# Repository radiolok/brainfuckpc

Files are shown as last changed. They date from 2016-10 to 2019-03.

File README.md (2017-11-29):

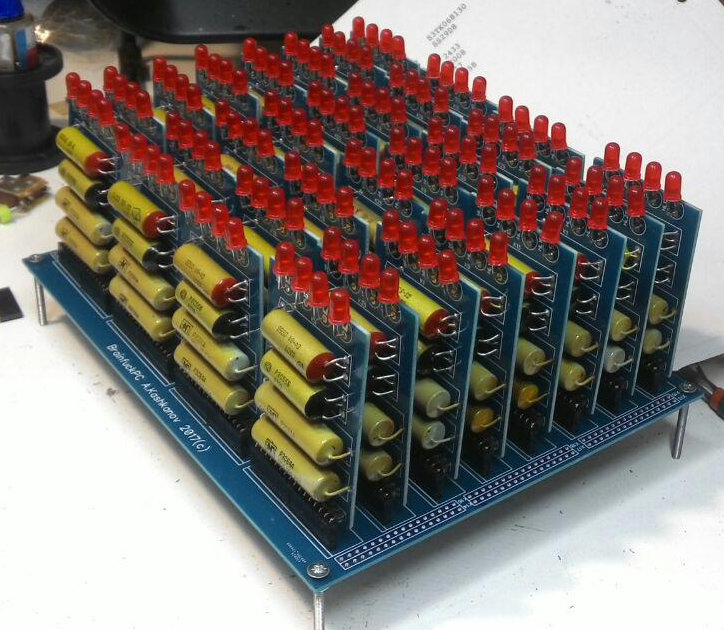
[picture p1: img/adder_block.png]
Adder block


Adder block photo

# GENERAL INFORMATION

* Von-neuman 16-bit architecture

* Brainfuck instruction set with RLE support and additional commands [(see instruction set DRAFT)](/doc/instruction_set.md)

* 16-bit Address space - rev.1 would use 65536 x 16 SRAM, rev.2 would have ferrite core memory;

* 16-bit Instruction length;

* 16-bit Data, with 8-bit backward-compatibility mode for executing 8-bit programms;

* Use reed relay only - soviet RES55 and RES64;

* One adder - 256 relays, 4 registers - 48 relay each, and instruction decoding logic takes about 200 relays ~= 700 relays.

* Clock frequency up to 100 Hz.

# BRAINFUCK

Brainfuck is an esoteric programming language created in 1993 by Urban Müller, and notable for its extreme minimalism.

The language consists of only eight simple commands and an instruction pointer. While it is fully Turing-complete, it is not intended for practical use, but to challenge and amuse programmers.

The language's name is a reference to the slang term brainfuck, which refers to things so complicated or unusual that they exceed the limits of one's understanding.

Classic Brainfuck arch has eight commands:

* \>	increment the address pointer (to point to the next cell to the right).

* <	decrement the address pointer (to point to the next cell to the left).

* \+	increment (increase by one) the byte at the address pointer.

* \-	decrement (decrease by one) the byte at the address pointer.

* .	output the byte at the address pointer.

* ,	accept one byte of input, storing its value in the byte at the address pointer.

* \[	if the byte at the address pointer is zero, then instead of moving the instruction pointer forward to the next command, jump it forward to the command after the matching ] command.

* ]	if the byte at the address pointer is nonzero, then instead of moving the instruction pointer forward to the next command, jump it back to the command after the matching \[ command.

As each relay has very big latency I add RLE compressing of +- and <> commands.

If source file contain "+++++" or "-----" sequence, when listing will be loaded this sequence will be transformed into "+Constant" command - My computer has fully - functionaland 16-bit Adder for Data/Address/Instruction and this hack improve computer performance in many times.

Loop command are work as JZ to the end of the cycle and JNZ to begin using second Adder input and 12-bit jump

Use DipTrace 2.3 or higher  to open project files

Use Splan 7 to open spl7 files - there are some structures.

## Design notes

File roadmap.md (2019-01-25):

# 1. PCB Making[DEPRACATED]

I have no time to finish self-maid boards so ordered full set of pcb's:
10 pcb - base boards
10 plates with 24 different modules on each - 240 modules
2AND/2XOR
2AND/2OR
D-trigger
2&(3C+1A)
Diode(8)

## Equipment
1. Roaster temperature regulator - Done
2. Solder mask frame table   - Done
3. Etching bath - Ok
4. CNC milling machine tuning - Not finished yet
5. 3D printer - In use

# 2. Soldering
| Module | Components  | Soldered | Status |
|---|---|---|---|
|2AND/2OR |  Check  | 22 |  Done |
|2AND/2XOR |  Check  | 32 |  Done |
|D-TRIGGER |  Check | 67 |  Done |
|2& | Check  | 20 |  Done |
|Diode module |  Check  | 20 |  Done |
|Base board |  Check | 5/6 |  Done |
|Memory board |  Check | 1/1 |  Done |
|Indicator module |  Check | 4/4 |  Done |
|Latch module |  Check | 8/8 |  Done |

## Equipment
1. Relay tester - Done
2. Modules tester - Done

# 3. Wire Wrapping
|Block | Status | 
|---|---|
|ADD |  DONE  |
|IP/AP REG |  DONE  |
|TMP/CMD REG |  DONE  |
|LOGIC BLOCK |  Active |
|LOGIC/SWITCH BLOCK  |  Active  |

# 4. Memory Board 
| Operation |  Status |
|---|---|
| Schematic |  Done |
| PCB Routing |  Done |
| MCU firmware |  Active  |

# 5. Housing
|  Component | Status |
|---|---|
| Base Plate | Done |
| Main Frame | Done |

# 6. Progress updates:

## Update 12/1/2019:
* BFPC Frame is done, and all computer parts are placed on chassis;
* Memory board is working enough for BFPC start;
* Logic blocks are 30% done

## Update 24/05/2018:
* D-triggers for TMP/CMD register block done;
* All block housings are printed;
* Indicator boards assembly finished;
* Soldered all latch modules;

## Update 26/02/2018:
* Adder Block done and tested;
* IP/AP register block done and tested;
* Continue soldering D-trigger modules;
* Created indicator modules. Soldered two of them. Fw for one is done;
* Created latch modules. Soldered two of them;
* Start working with memory board firmware.

## Update 14/12/2017:
* Soldering D-trigger modules. Need 64+, got half of them
* Designed indicator board
* Start wire-wrap of adder block

## Update 12/11/2017:
* Ordered pcbs from easyeda and got it.
* Soldered all 2AND/2XOR modules for carry-chain adder. Start soldering base plate for it.
* Done with modules tester - didn't check any relay but will check all modules.

## Update 05/06/2017:
* Only in third attempt I painted some boards with solder mask. It's a diode module, 2ANDx4 module and 2& module - two plates of each type. Currently can start drill and mill them and start assemble the modules.

## Update 17/04/2017:
* Rework and optimized ADDer logic. previous version needed 64 modules with 3 different types: ADD+C, 5AND, 2AND/2OR. New version need 32 modules with 2AND/2XOR type; One basic block would be used for latches.
* Done with memory Board module routing - Already got ready pcb from manufacturer and currently soldering it.
* Done with prepearing for solder mask operations - will start with this one as soon possible;
* Thinking about memory module firmware. Start developing it's arch.

## Update 08/03/2017:
* I'm done with all known modules etching 30 pcbs! All adder modules, all register modules are ecthed;
* Created and etched some modules for logic block - I have 64 modules capacity on it and have only preliminarty schematic for microcode;
* Next step - apply solder mask on them and send to drilling and milling. After this steps I will start soldering modules.

## Update 04/03/2017:
* Put image on another 6 plates and want to etch them in near future - 3x5AND, 1x2AND/2OR, 2xD-trigger.
* Almost finished with Memory Board routing. Need to fix power lines and check all connections.
* Prepare plywood table for photomask - it's ready for use and I want to start when finished with all known boards.

## Update 25/02/2017:
* Etched additional 12 pcb's - 6 pcb of D-trigger, 2 ADD+C, 1 5AND, 3 base boards.

## Update 23/02/2017:
* Suddenly found that I have D-trigger unrouted yet. Fix this issue and got one-side pcb with one jumper. Printed Photomasks and Imaged two plates;
* Modified ADD+C routing into one-side pcb with one jumper. Reprinted photomasks and made one of two Images;
* Bought thermal laminator for doing photoresist operations better - when I start etching I found that they are a lot of issues with images quality. First test gaves me stable good image quality after I just found proper temperature;
* Currently I have 5 etched plates and 7 - waiting for etch (will do it in 2-3 days).

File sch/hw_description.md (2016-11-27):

#Parts

Computer consists of many different unified basic modules 60x44mm with 16x2.54mm male socket. 
Each module contains 4 reed relays, status LED's and diode binding for each relay.

## Modules types:

* 1bit ADD+C module for adder - 16 modules;
* 5AND module for parallel carry - 32 modules;
* Universal 2AND/2OR module for adder and control logic - 16 modules(for Adder);
* 1bit D-trigger with inversion for temp register - 16 modules;
* 1bit D-trigger with Output switch, for IP and AP register, Bias register and command register - 48 modules;
* Some other modules, which I din't implemented yet (list is updated)

## Base Plates:

Modules are mounted on base plates, 32 modules on each 150x200m base plate. Current implementation requers 7 base plates:

* Base plate with 32 16pin connectiors - 5 base plates;
* Switching plate with only 8 16-pin connectors, but with 4 16 bit switches - 1 plate;
* Memory plate with static RAM IC, input and output buffers and MCU with LED drivers for LED 16x32dot disdplay;

I will made all connection with wire-wrapping method.

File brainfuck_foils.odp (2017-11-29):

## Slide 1

16-bit

FULL ADDER with CARRY

IP REG

AP REG

(16bit)

RAM, CIN, COUT

MCU loader, LED display,

Wi-Fi& USB Connection

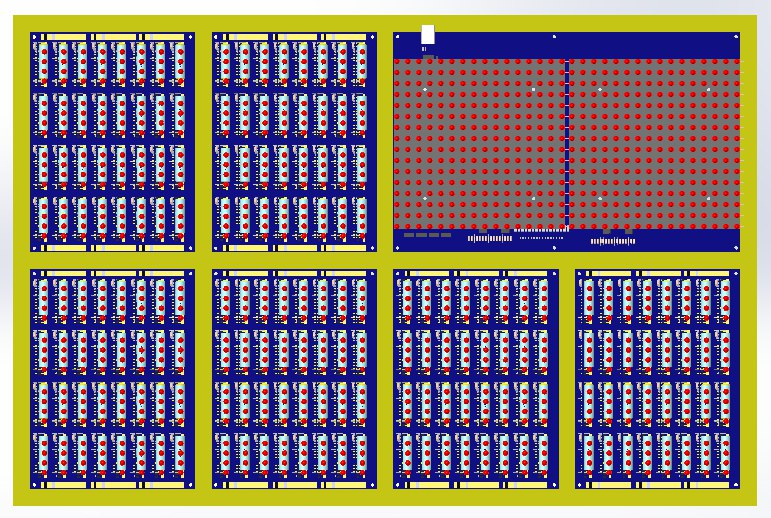
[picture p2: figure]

TMP REG

(16bit)

CMD REG

(12+4bit)

SEQUENCER,

CMD SELECTOR

and some other logic

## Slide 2

ADDRESS BUS

TMP

REG

16bit

IP

REG

16bit

RAM

64K

x16bit

COUT

CIN

ADDER

+

CARRY

AP

REG

16bit

CMD

REG

12bit

4bit

LOGIC

DATA BUS

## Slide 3

RAM Main Flow

Address input buffer

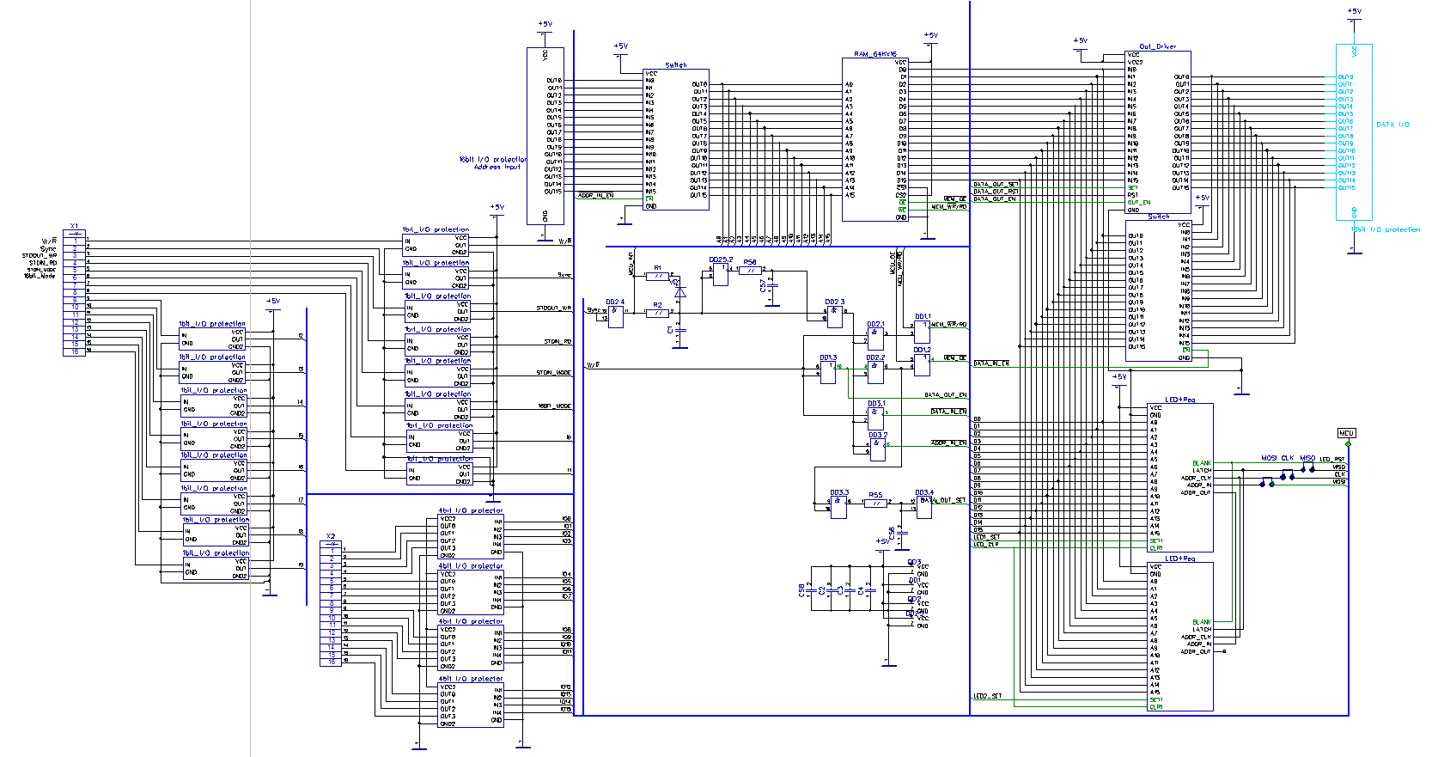
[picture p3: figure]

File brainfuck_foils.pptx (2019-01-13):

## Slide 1

16-bit
FULL ADDER with CARRY

IP REG
AP REG
(16bit)

RAM, CIN, COUT
MCU loader, LED display,
Wi-Fi& USB Connection


TMP REG
(16bit)
CMD REG
(12+4bit)

SEQUENCER,
CMD SELECTOR
and some other logic

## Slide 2

16 bit ADDRESS BUS

IP
REG
16bit

RAM
64K
x16bit

COUT

CIN

TMP
REG
16bit

ADDER
+
CARRY

AP
REG
16bit

CMD
REG
12bit

4bit

CMD LOGIC

16 bit DATA BUS

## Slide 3

RAM Main Flow


Address input buffer

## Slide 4

Word-length register

IP Cache

Cache
valid

Cache
invalid

<<[>[>+>+<<-]>>[<<+>>-]<<<-]

Cache
Invalidated here

Yes

IP = IP + 1

*AP==0?

No

Invalidate
Cache

IP Cache is valid?

Yes

No

IP = IP Cache + 1

Left IP Lookup

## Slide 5

Cache
valid

Cache
invalid

<<[>[>+>+<<-]>>[<<+>>-]<<<-]

innerLoop1

innerLoop2

need to find
This IP address

outterLoop

*AP==0?

No

Cache
invalid

yes

Left IP Lookup

IP = IP + 1

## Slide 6

IP Cache

Cache
valid

Cache
invalid

<<[>[>+>+<<-]>>[<<+>>-]<<<-]

IpStack=0

IpStack=1

IpStack=2

IpStack=1

IpStack=2

IpStack=1

do
{
IP = IP-1;
if (‘]’)
IpStack++;
if (‘[’)
IpStack--;
}while(IpStack!=0)

Left IP Lookup

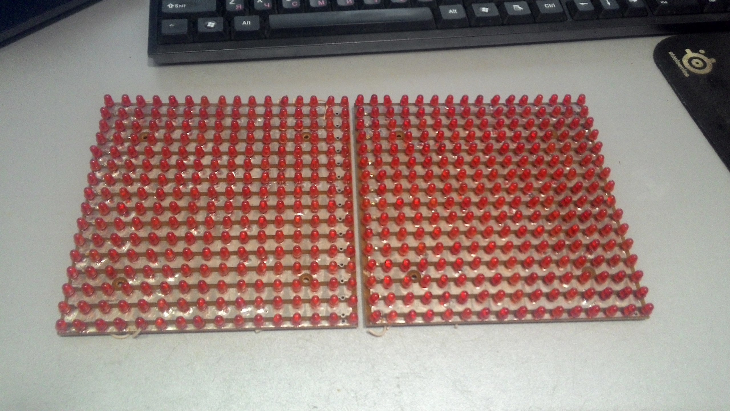
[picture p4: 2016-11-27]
img/display.jpg

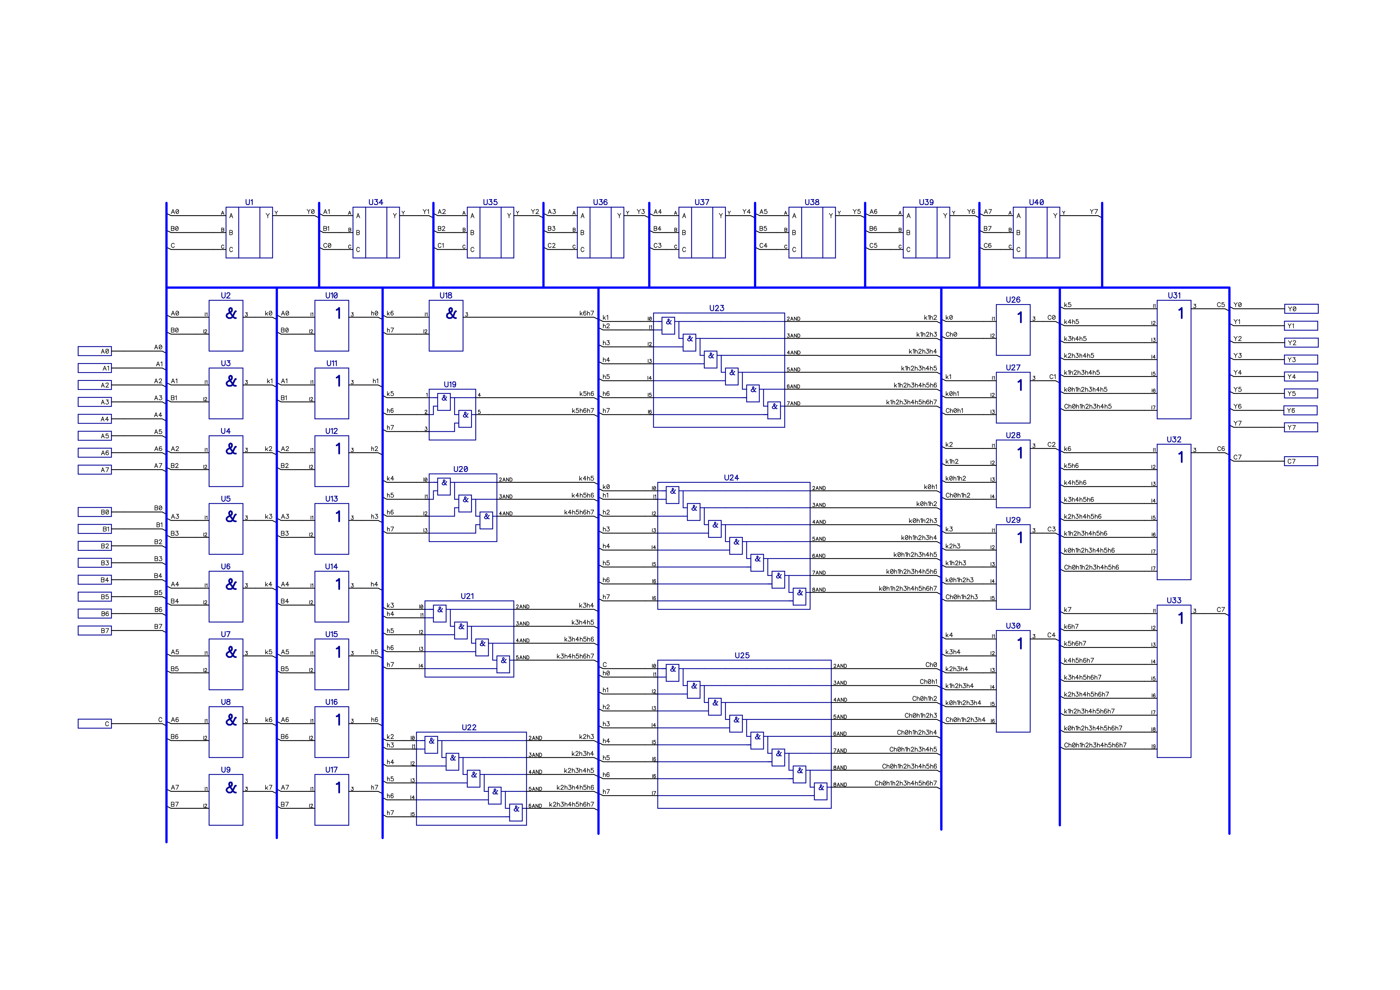
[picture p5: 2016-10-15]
img/8bit_ADD+parallel_C.png

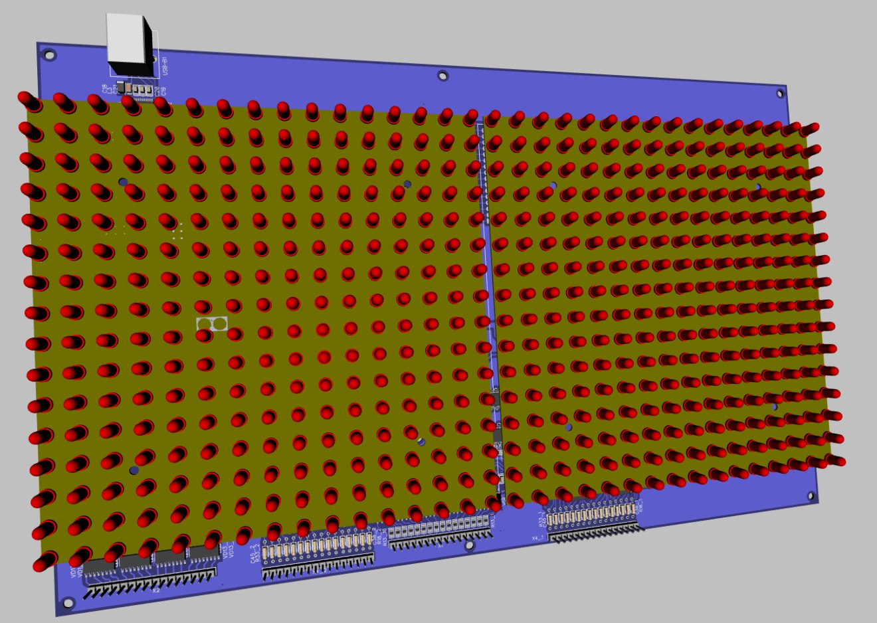
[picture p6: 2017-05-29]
img/memorybrd_3d_top.jpg

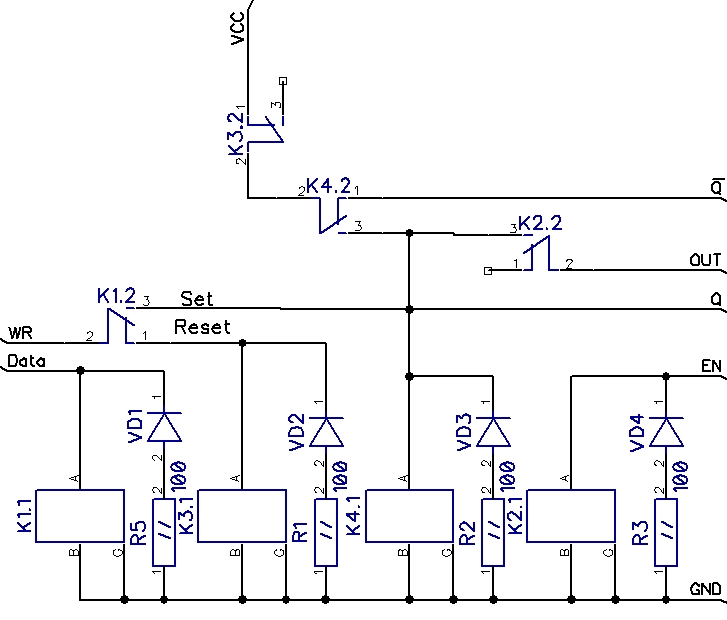
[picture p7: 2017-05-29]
img/reg.jpg

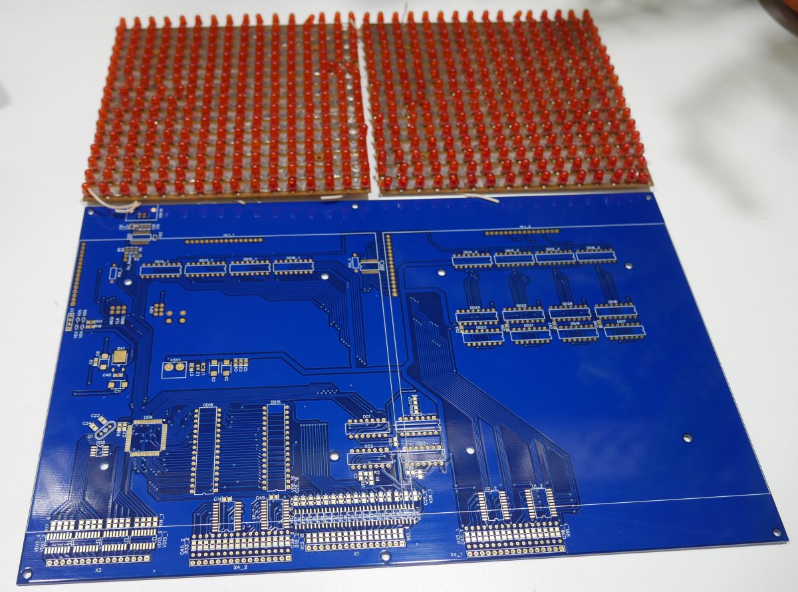
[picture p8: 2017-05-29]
img/memory_brd_real_1.jpg

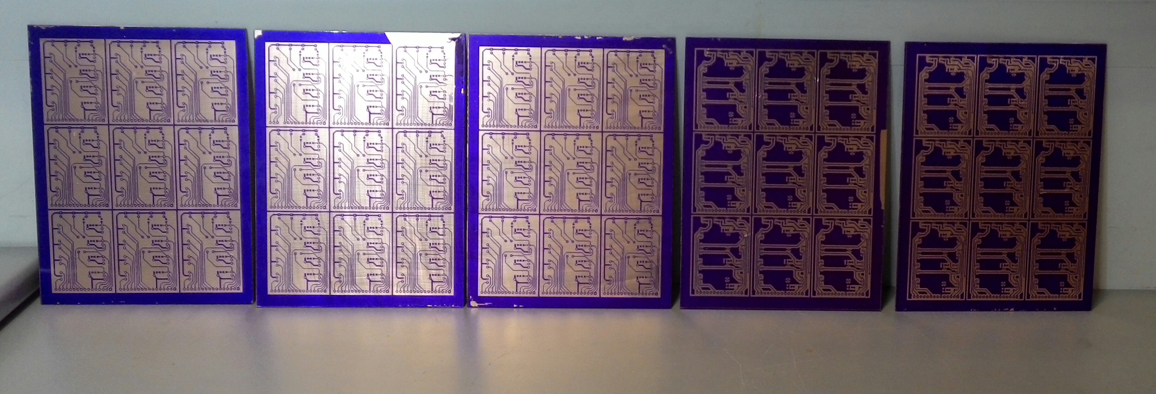
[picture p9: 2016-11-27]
img/pcb_work.jpg

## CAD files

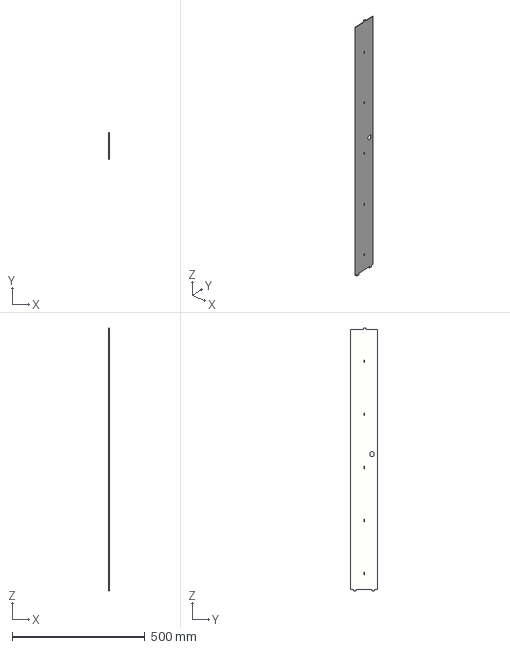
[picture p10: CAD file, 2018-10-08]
doc/Chassis/stp/Support_Right.step
2.00 x 100.0 x 992.2 mm

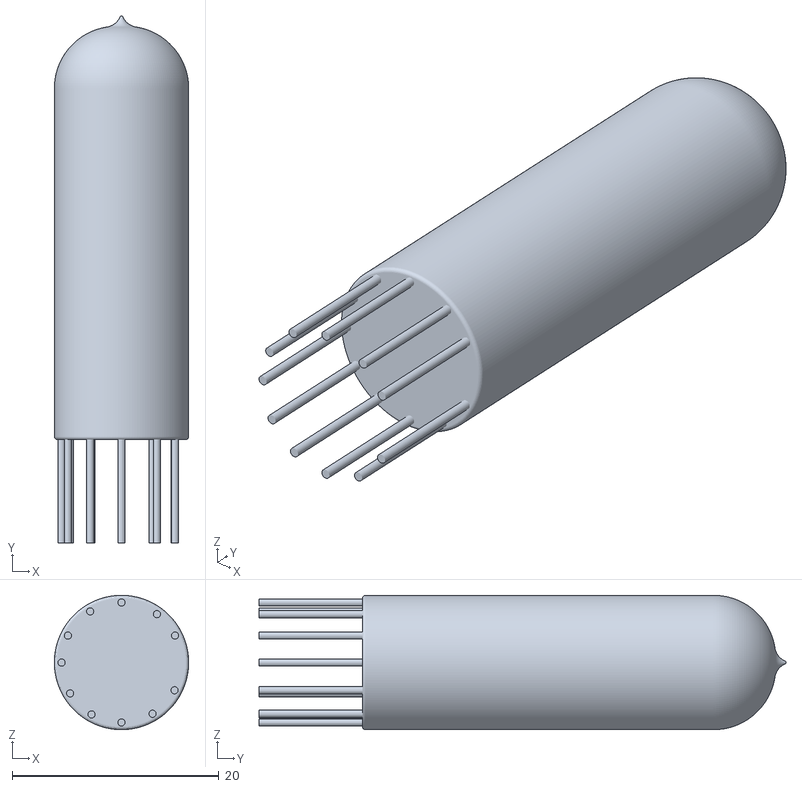
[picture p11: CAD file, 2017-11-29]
img/iv6 v1.stl
13.0 x 51.0 x 13.0

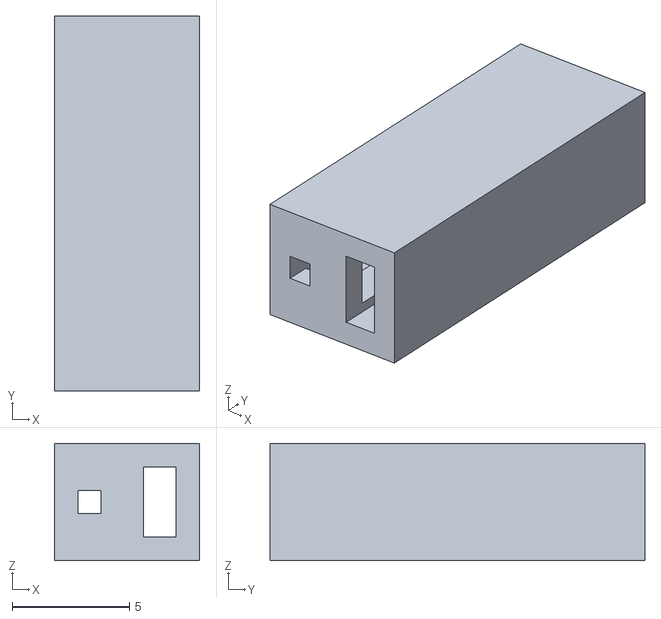
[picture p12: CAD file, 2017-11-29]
relay_tester_part v1.stl
6.20 x 16.0 x 5.00

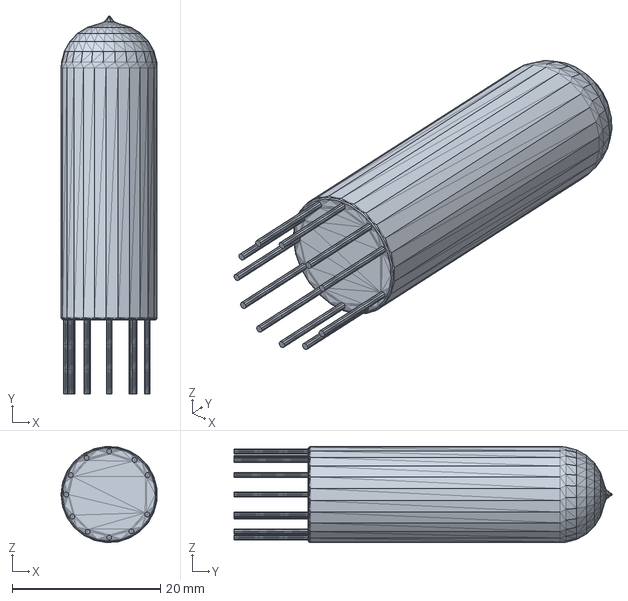
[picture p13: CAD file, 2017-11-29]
img/iv6.iges
12.9 x 51.0 x 13.0 mm

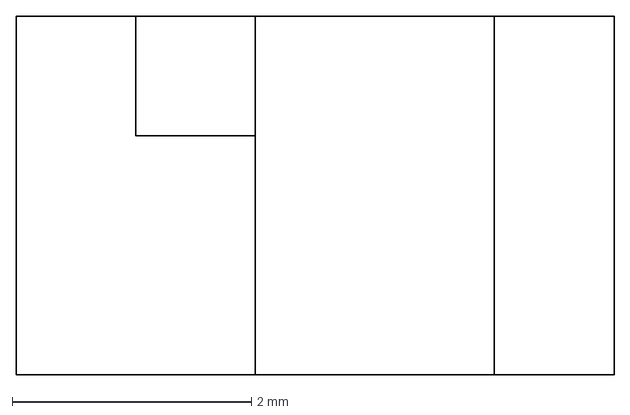
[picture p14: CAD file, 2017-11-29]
point.dxf
5.00 x 3.00 mm

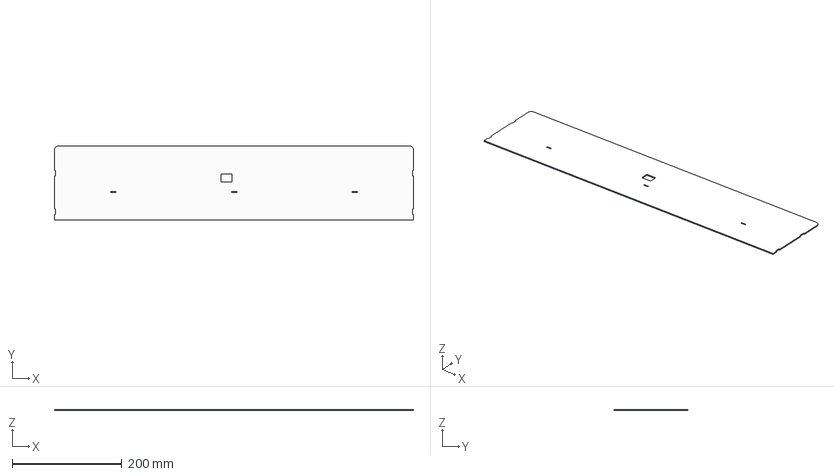
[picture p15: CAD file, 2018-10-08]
doc/Chassis/stp/Top.step
654.0 x 135.0 x 2.00 mm

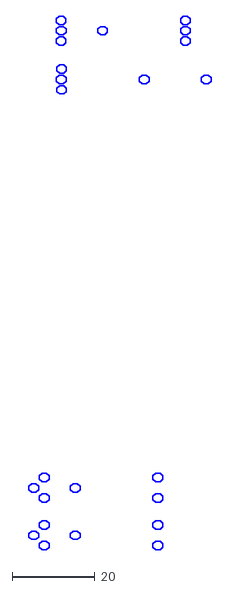
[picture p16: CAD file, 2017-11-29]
relay.dxf
44.0 x 129.1

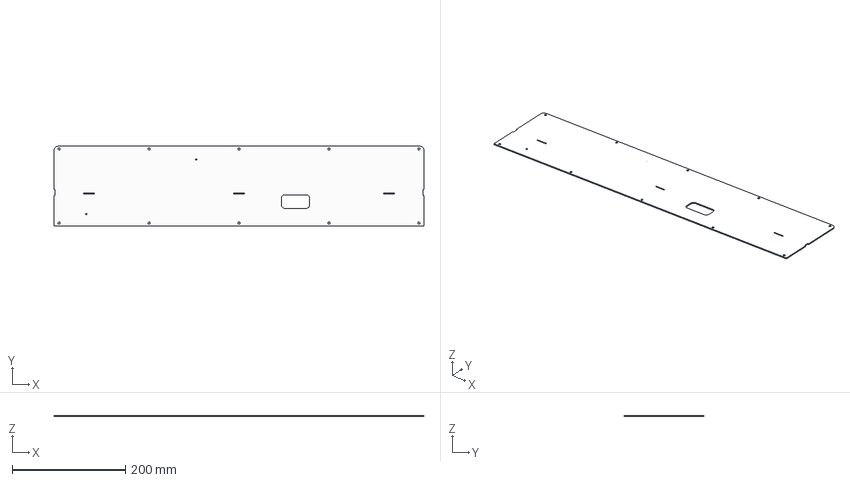
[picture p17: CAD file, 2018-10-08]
doc/Chassis/stp/Ground Plate.step
654.0 x 141.0 x 2.00 mm

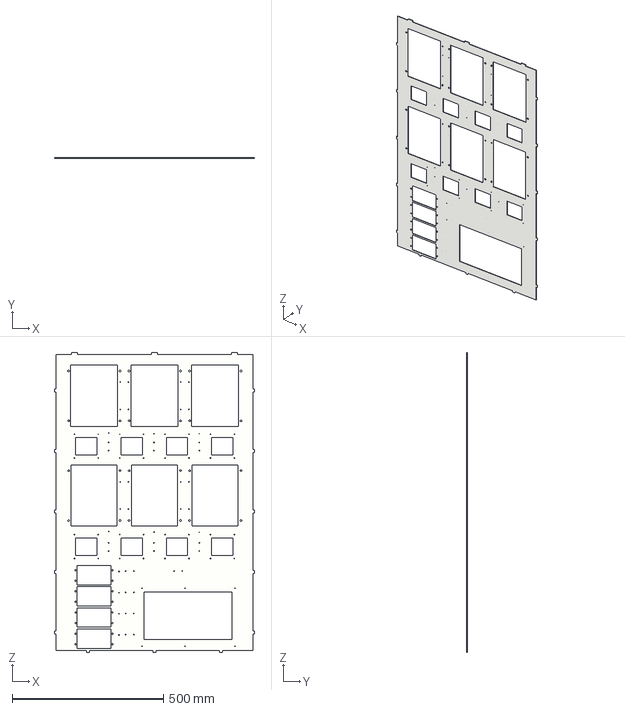
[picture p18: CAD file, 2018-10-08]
doc/Chassis/stp/Plate.step
662.0 x 2.00 x 992.0 mm

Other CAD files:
doc/Chassis/stp/Support_Left.step

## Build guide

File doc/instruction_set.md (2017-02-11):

#Overview

All instructions are 16-bit wide.

* Bits 15, 14, 13 - define instruction class
* Bit 12 - Signed bit
* Bits 11-0 - contain least 12bit of signed integer. Master 4 bits generates automatically: 0 for positive and 1 for negative values.

# Assembler instruction set

|Instruction |Opcode | Operation| Brainfuck Equivalent | Description|
|---|---|---|---|---|
|add m16 |0X XX  |*AP ← *AP + m16 | '+' (Repeat m16 times) | Add base to current data value |
|sub m16 |1X XX  |*AP ← *AP - m16 | '-' (Repeat m16 times) | Substract base from  current data value |
|ada m16 |2X XX  |AP ← AP + m16 | '>' (Repeat m16 times) | Increase memory address |
|ads m16 |3X XX  |AP ← AP - m16 | '<' (Repeat m16 times) | Decrease memory address |
|jz m16 |4X XX  |(*AP == 0)? IP ← IP + m16 : IP ← IP | '['  | Jump to IP + m16 if  current data value is zero |
|jz m16 |5X XX  |(*AP == 0)? IP ← IP - m16 : IP ← IP | None  | Jump to IP - m16 if  current data value is zero |
|jnz m16 |6X XX  |(*AP != 0)? IP ← IP + m16 : IP ← IP | None  | Jump to IP + m16 if  current data value is not zero |
|jnz m16 |7X XX  |(*AP != 0)? IP ← IP - m16 : IP ← IP | ']'  | Jump to IP - m16 if  current data value is not zero |
|and m16 |8X XX  |*AP ← *AP AND m16 | None | Logical AND of current data value with positive constant|
|and m16 |9X XX  |*AP ← *AP AND m16 | None | Logical AND of current data value with negative constant|
|or m16 |aX XX  |*AP ← *AP OR m16 | None | Logical OR of current data value with positive constant|
|or m16 |bX XX  |*AP ← *AP OR m16 | None | Logical OR of current data value with negative constant|
|in |c0 00  |*AP ← CIN  | ','  | Read one m8 symbol from console. If Cin buffer is empty, wait it |
|out |c0 01  |COUT ← *AP | '.'  | Write m8 symbol to console |
|clr.ap |d0 01  |AP ← 0 | None  | Clear AP register. Can be combined with other clr commands |
|clr.ip |d0 02  |IP ← 0 | None  | Clear IP register. Can be combined with other clr commands |
|clr.dp |d0 04  |*AP ← 0 | '[+]' or '[-]'  | Clear current data cell. Can be combined with other clr commands |
|set.ap |d0 10  |AP ← *AP | None  | Write current data value to AP register |
|set.ip |d0 20  |IP ← *AP | None  | Write current data value to IP register |
|get.ap |d1 00  |*AP ← AP | None  | Read current data value from AP register |
|get.ip |d2 00  |*AP ← IP | None  | Read current data value from IP register |
|mode.b8 |e1 00  | | None  | 8-bit mode activated(1)  |
|mode.b16 |e2 00  | | None  | 16-bit mode activated |
|halt |f0 00  | | None  | halt machine |

* AP - Address pointer Register
* IP - Instruction pointer register
* *AP - Current Data cell
* CIN - Console input
* COUT - console output

1. When 8-bit mode activated all arithimetic operations continue to perform in 16-bit mode. But JZ and JNZ branches start depends on only least data byte -  (DP & 0x00FF == 0)? and (DP & 0x00FF != 0)? Console Input and Output are always read and write only least byte of 16-bit Word.

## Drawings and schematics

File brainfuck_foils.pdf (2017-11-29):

16-bit
FULL ADDER
with CARRY

IP REG
AP REG
(16bit)

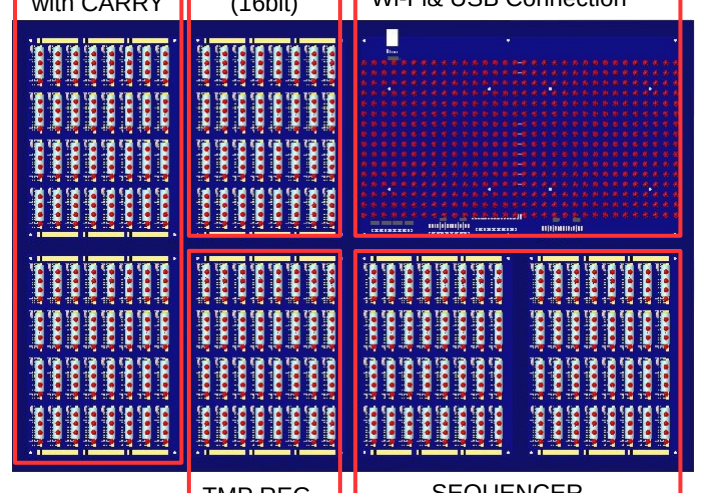
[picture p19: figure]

TMP REG
(16bit)
CMD REG
(12+4bit)

SEQUENCER,
CMD SELECTOR
and some other logic

RAM, CIN, COUT
MCU loader, LED display,
Wi-Fi& USB Connection

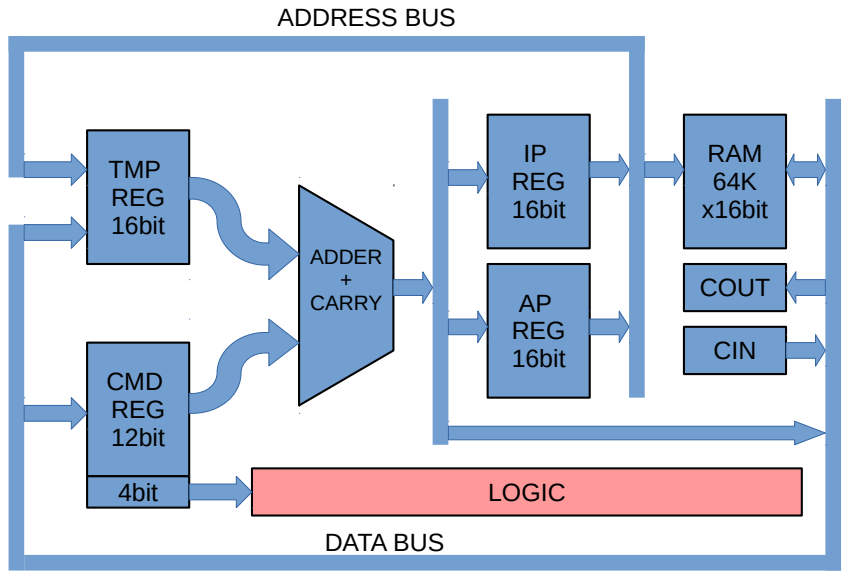
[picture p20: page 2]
TMP REG 16bit; CMD REG 12bit; 4bit; ADDER + CARRY; IP REG 16bit; AP REG 16bit; RAM 64K x16bit; COUT; CIN; DATA BUS; ADDRESS BUS; LOGIC

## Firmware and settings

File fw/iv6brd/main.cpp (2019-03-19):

/*
 * iv6brd.cpp
 *
 * Created: 14.12.2017 22:57:47
 * Author : radiolok
 */ 

#include <avr/io.h>



//#define COUNTER 1

//#define SHOWER

#if defined(TERMINAL)
#define BAUD_RATE 9600
#else
#define BAUD_RATE 38400
#endif

#include "MTask.h"
#include "log.h"
#include "uart.h"
#include "spi.h"
#include "SegmentDisplay.h"

//#define IP_SHOW
//#define AP_SHOW
//#define CMD_SHOW

#if defined(IP_SHOW)
char prefix[] = "I ";
char length = 2;
#elif defined(AP_SHOW)
char prefix[] = "A ";
char length = 2;
#elif defined(CMD_SHOW)
char prefix[] = "C ";
char length = 2;
#else
char prefix[] = "  ";
char length = 2;
#endif

#if defined (SHOWER) || defined(COUNTER)
	static uint32_t SCHEDULER_PERIOD = 1;//ms
#endif


void portReader()
{


	
#if  defined(SHOWER)
	DDRB |= (1<<PB2);
	//read current value
	PORTB &= ~(1<<PB2);
	_delay_us(1);
	PORTB |= (1<<PB2);
	
	union data_t{
		uint8_t bytes[2];
		uint16_t word;		
	} data;
		data.bytes[0] = spi_sendByte(0);
		data.bytes[1] = spi_sendByte(0);
		
	SegmentDisplay::Instance()(data.word, prefix, length);

	
	
#endif

}

/*
Backspace (without delete function) BS
Line feed LF
Carriage Return CR
Clear display ESC [2J
Positioning the character pointer ESC [Py; PxH
Delete until end of line ESC [0K
Set country code ESC Rn
Get Display ID ESC [0c

*/


#if defined(TERMINAL)

#define ChESC  0x1B

void clearDisplay()
{
	uart_putc(ChESC);
	uart_puts("[2J");
}

void setPosition(uint8_t x, uint8_t y)
{
	uart_putc(ChESC);
	uart_putc('[');
	uart_putc(x);
	uart_putc(';');
	uart_putc(y);
	uart_putc('H');
}

#endif


#if defined(SHOWER)
void shower()
{
	sei();
	uart_init(UART_BAUD_SELECT(BAUD_RATE, F_CPU));
	

	MTask::Instance().Init(SCHEDULER_PERIOD, F_CPU);
	spi_init();

	SegmentDisplay::Instance().Init(6, 0x10);
	MTask::Instance().Add(portReader, 0, 5);

	/* Replace with your application code */
	MTask::Instance().Start();

}
#elif defined(TERMINAL)
void terminal()
{
	
	/*
	BIT 0 PB2
	BIT 1 PB1
	BIT 2 PB0
	BIT 3 PD7
	BIT 4 PD6
	BIT 5 PD5 
	BIT 6 PB7
	BIT 7 PB6
	*/
	sei();
	uart_init(UART_BAUD_SELECT(BAUD_RATE, F_CPU));
	uart_set_parity(UART_PARITY_ODD);
	uint8_t old_state = 0;
	
	uint8_t symbols = 0;
	
	uart_puts("hello world!");
	while(1)
	{
		uint8_t state = PINC & (1<<PC1);
		if ( state != old_state)
		{
			if (state)
			{
				uint8_t pinB = PINB;
				uint8_t pinD = PIND;
				
				uint8_t result = 0;
				
				result |= ((pinB >>PB2) & 0x01);
				result |= (((pinB >>PB1) & 0x01) << 1);
				result |= (((pinB >>PB0) & 0x01) << 2);
				result |= (((pinD >>PD7) & 0x01) << 3);
				result |= (((pinD >>PD6) & 0x01) << 4);
				result |= (((pinD >>PD5) & 0x01) << 5);
				result |= (((pinB >>PB7) & 0x01) << 6);
				result |= (((pinB >>PB6) & 0x01) << 7);
				
				symbols++;					
				if (result == 0x0A)
				{
					uart_putc(0x0D);
					symbols = 0;
				}				
				uart_putc(result);			


				if (symbols > 19)
				{
					uart_puts("\r\n");
				}
			}
			_delay_ms(1);
		}		
		old_state = state;

	}
}
#elif defined(COUNTER)

volatile uint32_t instructions_retired = 0;

uint8_t old_state = 0;
void clock_checker()
{
	uint8_t state = PINB & (1<<PB1);
	if ((state) && (state != old_state))
	{
		instructions_retired++;
		SegmentDisplay::Instance()(instructions_retired);
	}
	old_state = state;
}

void counter(void)
{
	sei();


	MTask::Instance().Init(SCHEDULER_PERIOD, F_CPU);

	SegmentDisplay::Instance().Init(6, 10);
	
	SegmentDisplay::Instance()(0L);
	
	MTask::Instance().Add(clock_checker, 0, 1);

	/* Replace with your application code */
	MTask::Instance().Start();
	
}
#endif

int main(void)
{
#if defined(TERMINAL)
	terminal();
#elif defined(SHOWER)
	shower();
#elif defined(COUNTER)
	counter();
#else
	#error "No type defined!"
#endif
	
}

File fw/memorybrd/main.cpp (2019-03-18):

/*Copyright (c) 2013-2017, Artem Kashkanov
All rights reserved.
Redistribution and use in source and binary forms, with or without modification, are permitted 
provided that the following conditions are met:
1. Redistributions of source code must retain the above copyright notice, this list of 
conditions and the following disclaimer.
2. Redistributions in binary form must reproduce the above copyright notice, this list 
of conditions and the following disclaimer in the documentation and/or other materials 
provided with the distribution.
THIS SOFTWARE IS PROVIDED BY THE COPYRIGHT HOLDERS AND CONTRIBUTORS "AS IS" AND ANY EXPRESS OR 
IMPLIED WARRANTIES, INCLUDING, BUT NOT LIMITED TO, THE IMPLIED WARRANTIES OF MERCHANTABILITY AND 
FITNESS FOR A PARTICULAR PURPOSE ARE DISCLAIMED. IN NO EVENT SHALL THE COPYRIGHT HOLDER OR CONTRIBUTORS 
BE LIABLE FOR ANY DIRECT, INDIRECT, INCIDENTAL, SPECIAL, EXEMPLARY, OR CONSEQUENTIAL DAMAGES 
(INCLUDING, BUT NOT LIMITED TO, PROCUREMENT OF SUBSTITUTE GOODS OR SERVICES; LOSS OF USE, DATA, 
OR PROFITS; OR BUSINESS INTERRUPTION) HOWEVER CAUSED AND ON ANY THEORY OF LIABILITY, WHETHER IN
 CONTRACT, STRICT LIABILITY, OR TORT (INCLUDING NEGLIGENCE OR OTHERWISE) ARISING IN ANY WAY OUT 
 OF THE USE OF THIS SOFTWARE, EVEN IF ADVISED OF THE POSSIBILITY OF SUCH DAMAGE.*/

#include "macros.h"

#include "MTask.h"
#include "log.h"
#include "uart.h"
#include "ram/ExternalRam.h"
#include "driver/led.h"
#include "driver/pinIO.h"
#include "midi.h"
#include "string.h"

static uint32_t SCHEDULER_PERIOD = 1;//ms


uint16_t helloworldApp[45] = {
	0x0000, 0x4400, 0x200a ,0x600b ,0x4001 ,0x2007 ,0x4001 ,0x200a ,0x4001 ,0x2003 ,0x4001 ,0x2001 ,
	0x5ffc ,0x3fff ,0x9ff5 ,0x4001 ,0x2002 ,0x1002 ,0x4001 ,0x2001 ,0x1002 ,0x2007 ,0x1002 ,
	0x1002 ,0x2003 ,0x1002 ,0x4001 ,0x2002 ,0x1002 ,0x5ffe ,0x200f ,0x1002 ,0x4001 ,0x1002 ,
	0x2003 ,0x1002 ,0x3ffa ,0x1002 ,0x3ff8 ,0x1002 ,0x4001 ,0x2001 ,0x1002 ,0x4001 ,0x1002 };

uint16_t calcpi[] = {
	0x0000, 0x4400, 0x2016, 0x4001, 0x2007, 
			0x6008, 
					0x4001, 0x2001, 0x5fff, 0x3fff,
					0x4002, 0x2001, 0x5ffe, 
			0x9ff8, 
			0x6002, 
					0x3fff, 
			0x9ffe, 
	0x5fff, 0x6022, 0x4002,
	0x6005, 0x4004, 0x2001, 0x5ffc, 0x3fff, 0x9ffb, 0x4004, 0x6008, 0x3fff, 0x5ffc,
	0x2001, 0x5ffe, 0x3fff, 0x6004, 0x4006, 0x9ff8, 0x5ffa, 0x0000, 0x4006, 0x6009,
	0x6005, 0x5ffa, 0x2001, 0x4006, 0x3fff, 0x9ffb, 0x5ffa, 0x8006, 0x0000, 0x5ffb,
	0x2001, 0x5fff, 0x9fde, 0x0000, 0x400a, 0x2050, 0x1002, 0x2019, 0x1002, 0x3fd4,
	0x1002, 0x5ff7, 0x2030, 0x1002, 0x4009, 0x3ff1, 0x1002,
	0x5ff6, 0x3ffc, 0x1100, 0x6056, 0x3fff, 0x4001, 0x6002,
	0x3fff, 0x9ffe, 0x4001, 0x6005, 0x3fff, 0x5fff, 0x200a, 0x4001, 0x9ffb, 0x4001,
	0x6008, 0x4001, 0x2001, 0x5fff, 0x3fff, 0x4002, 0x2001, 0x5ffe, 0x9ff8, 0x4003,
	0x6002, 0x3fff, 0x9ffe, 0x5ffb, 0x6022, 0x4004, 0x6005, 0x4006, 0x2001, 0x5ffa,
	0x3fff, 0x9ffb, 0x4006, 0x6008, 0x3fff, 0x5ffa, 0x2001, 0x5ffc, 0x3fff, 0x6004,
	0x400a, 0x9ff8, 0x5ff6, 0x0000, 0x400a, 0x6009, 0x6005, 0x5ff6, 0x2001, 0x400a,
	0x3fff, 0x9ffb, 0x5ff6, 0x8006, 0x0000, 0x5ffb, 0x2001, 0x5ffb, 0x9fde, 0x0000,
	0x4004, 0x6005, 0x5ffd, 0x2001, 0x4003, 0x3fff, 0x9ffb, 0x4001, 0x2030, 0x1002,
	0x4001, 0x6002, 0x3fff, 0x9ffe, 0x5ffd, 0x6005, 0x5fff, 0x2001, 0x4001, 0x3fff,
	0x9ffb, 0x5ffc, 0x9faa, 0x200a, 0x1002, 0x2003, 0x1002, 0x1800 };


uint16_t check[45] = {0x00};

uint8_t getStdInMode()
{
	static uint8_t Stdin_mode = 0;
	static uint8_t Stdin_mode_old = 0;
	Stdin_mode = getInputPin((uint8_t)PinExtIn::STDIN_MODE);
	if (Stdin_mode != Stdin_mode_old)
	{
		if (Stdin_mode == true)
		{
			log_trace("StdIn Mode 16 bit!");
		}
		else
		{
			log_trace("StdIn Mode 8 bit!");
		}
	}
	Stdin_mode_old = Stdin_mode;
	return Stdin_mode;
}

uint8_t getStdRd()
{
	static uint8_t Stdin_mode = 0;
	Stdin_mode = getInputPin((uint8_t)PinExtIn::STDIN_RD);

	return Stdin_mode;
}

uint8_t getStdWr()
{
	static uint8_t Stdin_mode = 0;
	Stdin_mode = getInputPin((uint8_t)PinExtIn::STDOUT_WR);
	return Stdin_mode;
}

uint8_t getWriteMode()
{
	static uint8_t Write_mode = 0;
	Write_mode = getInputPin((uint8_t)PinExtIn::WR);

	return Write_mode;
}

uint8_t getSyncMode()
{
	static uint8_t Sync_mode = 0;

	Sync_mode = getInputPin((uint8_t)PinExtIn::Sync);

	return Sync_mode;
}



void loadTestFw()
{
	uint16_t addr = 0;
	ramWriteWord(addr++, 0);
	ramWriteWord(addr++, 0x5F00);
	/*for (uint16_t j = 1; j < 0x1000; j++)
	{
		ramWriteWord(addr++, (j % 0x10)? 0x2001 : 0x3FF1);
	}
	*/
	ramWriteWord(addr++, 0x2030);//
	ramWriteWord(addr++, 0x6002);
	ramWriteWord(addr++, 0x2001);
	ramWriteWord(addr++, 0x1002);
	ramWriteWord(addr++, 0x9FFC);
	
	
	for (uint16_t j = 0; j < 0x10; j++)
	{
		ramWriteWord(addr++, 0x2001);//ADD+1
		if (j != 0xF)
			ramWriteWord(addr++, 0x4001);//ADA+1
	}
	ramWriteWord(addr++, 0x5FF1);
	ramWriteWord(addr++, 0x9FDF);

}


void loadHelloWorld()
{
	ramWriteWordBuffer(0, helloworldApp, sizeof(helloworldApp)/sizeof(uint16_t));
	
	ramReadWordBuffer(0, check, sizeof(check)/sizeof(uint16_t));
	
	uint32_t result = memcmp(helloworldApp, check, 88);
	
	if (!result)
	{
		log_trace("Hello World Application loaded succesfully!");
	}
	else
	{
		log_trace_val("Hello World Application loading failed!", result);
		for (uint16_t addr = 0; addr < 44; ++addr)
		{
			uart_puts("(0x");
			uart_print((int16_t)(addr ),16);
			uart_puts(")\t");
			uart_print((int16_t)helloworldApp[addr],16);
			uart_puts("\t");
			uart_print((int16_t)check[addr],16);
			uart_putc('\n');
		}
	}
}

void ramChecker()
{
	static uint16_t addr = sizeof(helloworldApp)/sizeof(uint16_t);
	if (getSyncMode() == false)
	{
		ramWriteWord(addr ,  addr);
		if (addr){
			uint16_t result;
			ramReadWord(addr, &result);
			uart_puts("(0x");
			uart_print((int16_t)(addr ),16);
			uart_puts(")=0x");
			uart_print((int16_t)result,16);
			
			if (( addr) == result)
			{
				uart_puts(" OK!");
			}
			else
			{
				uart_puts("Fail!");
			}
			uart_putc('\n');
		}
		addr++;	
	}
}



void GPinOutChecker()
{
	static uint8_t state = 0;
	static bool state1 = 0;
	static bool state2 = 0;
	static bool state4 = 0;
	static bool state8 = 0;
	static bool state16 = 0;
	static bool state32 = 0;
	
	SetOutputPin(15, state1);
	state1 ^= 1;
	
	if (!(state % 2))
	{
		SetOutputPin(14, state2);
		state2 ^= 1;
	}
	if (!(state % 4))
	{
		SetOutputPin(13, state4);
		state4 ^= 1;
	}
	if (!(state % 8))
	{
		SetOutputPin(12, state8);
		state8 ^= 1;
	}
	if (!(state % 16))
	{
		SetOutputPin(11, state16);
		state32 ^= 1;
	}
	if (!(state % 32))
	{
		SetOutputPin(10, state32);
		state32 ^= 1;
	}
	state++;
	if (state > 31)
		state = 0;
}
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

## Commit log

2015-05-28 ADD: DipTrace soviet relays libraries
2016-08-13 Add dev-board for custom relay logic creation
    Base-board can handle up to 96 relays res55 or res64 (you can solder any if you want).
    Relays are grouped into 6 arrays of 16 relays.
    On the left and on the right of pcb (which is 200x300mm) there is a 40pin 2.54mm connector with power and 2x8 relays hardrouted (with solder tie of course).
2016-10-15 ADD: One-bit ADD+C module based on 4 res-55 relays. Module is production-ready ADD: 5xAND module for summator with parallel shift. Module is production-ready
    MOD: fix some errors in old code
2016-10-16 Add files via upload
    ADD: Brainfuck main logic schematic image
2016-10-20 ADD: Stack 16-stage swicth based on 4-bit ALU and 4-to-16 Selector ADD: IP Sequencer ADD: ALU Sequencer ADD: Memory Pointer Sequencer
2016-10-23 LIB: Add 2x2OR 2x2AND, 2AND+3AND elements and footprints for them and for 1bit ADD+C. SCH: mod 1bit ADD+C connector for now any connector uses: first 5 pins for input last 5 pins(or more for 16-pin m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
    SCH: Create 16-bit ADD with parallel carry on basic modules
    It contain 64 modules (16 ADD+C 16 2OR+2AND and 32 5AND) based on two 200x150 plates or on one 200x300 plate
2016-10-24 ADD: 2x8-bit parallel switch. Can be used for 16-bit switching
2016-10-26 ADD: New version of D-trigger register which uses only 3 relays for D-trigger and one additional relay for output inversion. Delay - 1 tick
2016-10-27 ADD: New, Fully 16-bit Von Neumann architecture of my brainfuck machine Delete sparce parts but add some swithces to handle right adder logic. UPDATE: Main Logic schematic in img folder
    ADD: Some new Logic blocks into library
2016-11-02 ADD: 16Bit switch panel
2016-11-04 MOD: Rewrite ADD+C module into one-side pcb with bridges. FIX: footprint for RES55 complies to both variants of relay - RES55-A and RES55-B
2016-11-05 ADD: Universal 4-relay module on which you can create different logic elements:
    2AND
    2AND-NOT
    2OR
    2OR-NOT
    4AND
    4OR
    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
2016-11-12 Print photofilms
2016-11-27 ADD: Diode module, some images and add 12V color for main schematic
2017-01-06 Add led matrix display
2017-01-07 Redraw schematic with subblocks
2017-01-09 Add footprints for all components and did components first-placement
2017-01-13 reconnect led panels and routed theit ICs
2017-02-02 ADD: photomask and finish with roaster
    Printed photomasks for both Base boards.
    And as roaster temperature regulator was finished and video was done, set Done status for it.
2017-02-11 Fix for photomask printing
2017-02-11 Add: capacitors, esp and do some routing
2017-02-18 Etched five boards in new Etching bath
2017-02-23 ADD: D-trigger routing. One-side pcb with one jumper
2017-02-23 MOD: modify add+c module into one-side pcb with one jumper
2017-02-24 Imageded yet another 6 pcb's
2017-03-01 Modify and prerouted custom IO plus changed Led panels connectors
2017-03-04 Add: 2ANDx4 module for sequencer/switch
2017-03-04 Finished with memory Board routing! Need to check all connections and send it to pcb factory. It's too huge for home making
2017-03-05 Improve Mark layer view. Fix 0805 footprints, move component names, add connectors description
2017-03-08 Fix footprints for photofilm
2017-03-08 Fix: footprints for photofilm and add signature
2017-03-08 ADD: module 2AND where 3 relays are with 1C contact, so we can create 2AND-NOT elements.
2017-03-18 Finish wirh MemoryBrd routing. Prepare gerber files
    [MemoryBrd-Border.gbr, MemoryBrd-Bottom.gbr, MemoryBrd-BottomMark.gbr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]
2017-04-12 ADD: 2AND/2XOR module for Carry-chain Adder. Routed it with two jumpers
2017-09-03 MOD: LedPanel driver routine added with creation of many other files with useful functions
2017-11-17 Add switch module ad AV-6 module
2017-11-19 Finished with IV6 module and switch module
2017-11-27 Great information update for matching current PC logic
2017-11-29 Fix changes before repo refactoring
    [iv6 v1.stl, iv6.iges, point.dxf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]
2018-01-14 Fix minor bugs. Currently all system work.
    [SegmentDisplay.cpp, main.cpp, uart.cpp]
2018-01-17 Added simple spi wrapper, without interrupts and ring buffer compiled, not tested - maybe needed to fix bits order
    [main.cpp, spi.cpp]
2018-01-18 Add uart bootloader for iv6brd, fix spi read Currently board is working
    [main.cpp, spi.cpp]
2018-02-24 Init first work around memory board
2018-02-25 Fix memory access algorithm. Now it work
    [ExternalRam.cpp, main.cpp]
2018-02-25 Add some initial work with LED panel
2018-02-26 Add led matrix code
2018-02-27 One more pin SS - becone unusable. If SS pin is configured as input, it switch spi to slave mode and nothing works. Fix spi and now it send data to TLC, but no led is brighting now. think I have a ra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
    [ExternalRam.cpp, TLC5941.cpp, led.cpp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]
2018-09-18 Add driver module on regular relays because no one reed relay can driver 1Amp curremt
2018-10-08 ADD driver modules
2018-10-08 replace - symbol with null
    [SegmentDisplay.cpp]
2018-10-08 Chasiss parts stp file
    [Ground Plate.step, Plate.step, Support_Left.step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]
2018-11-26 Add 16-channel P-mos driver
2018-11-30 Add 16-bit drivers
2018-11-30 old memorybrd code - try to do some stuff and add external interrupt reaction
2019-01-08 Add TLC led driver workaround pcb fix
2019-01-08 Fix relay-based driver module
2019-01-08 Minor fixes in schematic and pcb's
2019-01-08 Working on Memory board firmware
2019-01-15 Replace TLC with STP
    [STP16CP05.cpp, led.cpp, main.cpp]
2019-01-25 Replace LED panel code with proper version. Add INT routine to catch Mem_Sync moment.
    [ExternalRam.cpp, led.cpp, main.cpp]
2019-02-08 Update RS-232 output module and did 100% of route of programmer. Additionally started working on Memory board.
2019-02-20 Fix jitter for terminal
    [main.cpp]
2019-02-21 Add calcPi application - It's just doing 355/113. Currently it's writen on C, but can be "easily" converted into brainfuck
2019-03-19 iv6brd: Fix build for every MCU
    [main.cpp]
2019-06-29 Traced Address and data lines of Memory board rev.2
2026-10-16 ci: build AVR firmwares and bfutils on every push
    - firmware job: apt avr-gcc, fw/build.sh, size report, hex/elf artifacts
    - toolchain job: builds bfpp/bfrun and runs bf/examples/hello.b
    - release job: attaches .hex files to v* tags
    - bump fw/bfutils to 51ad46a: the 2017 pin emitted the draft ISA
    encoding, current bfutils matches the hardware (0x200A, 0x600B...)
    Claude-Session: https://claude.ai/code/session_016pUBBt679KXco3F73XyVcx
2026-10-17 tools/youtube: fix recurring recognition errors in transcripts
    fixes.tsv holds regex rules for words the auto-captions always get wrong
    (the author's name, "релейный", Brainfuck, "декатрон", "сумматор"...).
    vtt2md.py applies them to each joined paragraph, so words split across
    caption lines are caught too; doc/videos regenerated.
    Claude-Session: https://claude.ai/code/session_01Y8trFGrrQhAFDLaNnEF1YF
2026-10-17 doc: add facts from the video transcripts
    Things said in the videos but missing from the three Habr articles, each
    with a link to the moment in the video:
    - architecture: the adder's final carry scheme (carry through relay
    contacts, replacing the 2017 lookahead), the control-logic blocks and the
    asynchronous impulse sequencer, the XOR latch, the plan for 50 Hz
    - hardware: where the relays came from, D-trigger internals, module tester,
    PCB order, base board rev.2, wire-wrap practice, power distribution and
    cables, IV-6 module details, relay drivers, frame history and the oak
    stand, ideas that were not built
    - videos.md / README: link the transcripts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
